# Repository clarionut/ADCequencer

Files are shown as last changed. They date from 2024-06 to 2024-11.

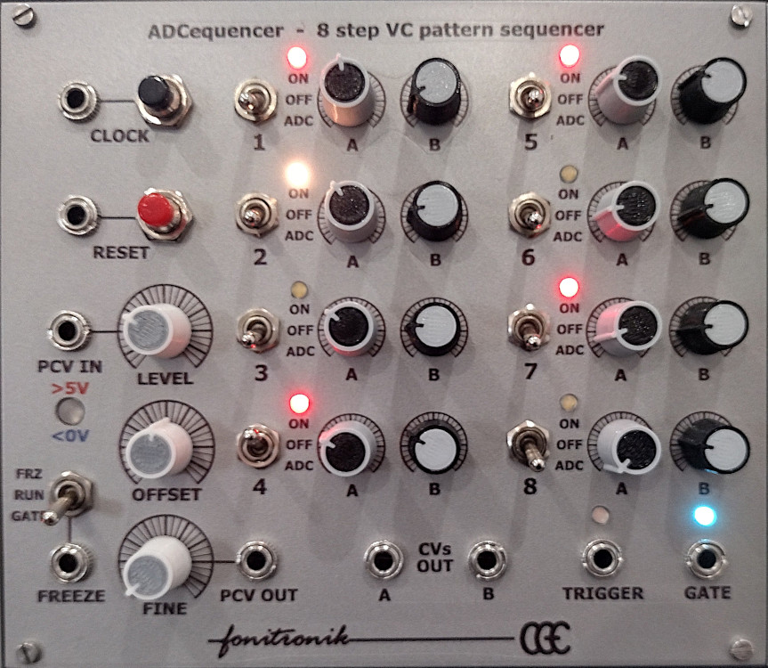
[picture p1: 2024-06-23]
Pictures/ADCequencer.jpg

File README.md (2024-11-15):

# ADCequencer
An 8 step dual channel sequencer with voltage controlled step pattern, based on the [Fonitronik VCPS8](http://www.modular.fonik.de/pdf/VCPS8_doc_v2.pdf) (the predecessor of the MH11) but with significant modifications.

Most obviously, there are two potentiometers to set CV voltages for each step and two CV output channels. This gives considerable flexibility - e.g. controlling two VCOs, a VCO and filter cutoff, or (in conjunction with an external clock divider / analogue switch module) operation as a 16-step sequencer.

Another significant visible change is the addition of a 'freeze' circuit operated by switch or a gate input allowing the ADC to be stopped under voltage control. This gives real value to the gate output from the VCPS8 (which is on continously through a sequence of active steps) as it allows the sequencer pattern to be updated only when the trigger output is low (generally meaning that no note is sounding). This avoids a serious glitchy effect when a step is turned off while it's active.

Cosmetically, the LED arrays have been replaced by red/white common-cathode bicolour LEDs associated with each step (red shows the active steps and white the current step) plus a red/blue common-anode LED as an indicator for out-of-range pattern control voltages.

Behind the scenes there are also significant changes:
- the PCV out-of-range protection circuit in the original is essentially a zener diode crowbar across an op-amp output. This has been replaced by an in-line resistor and Schottky diodes to +5V and ground. The PCV out is not clipped by these, so it's easy to use an external voltmeter to check and adjust the incoming control voltage. The out-of-range LED circuitry is also modified so the LEDs are never reverse biased.
- the Gray-coding circuitry is included but can be bypassed by connecting to an alternative header on the PCB. The CD4030 XOR gates can be omitted altogether if Gray-coding is not required.
- the gate/trigger driver circuit has been significantly revised, doing away with the need for the CD40106 in the original (discussion at [Electro-Music.com](https://electro-music.com/forum/topic-52774-50.html)). A simple RC filter on the base of the trigger-driver transistor removes the very fast pulse from the AND gates which can cause double-triggering. The CD40106 is not needed for the ADC clock either, as the ADC802 contains an inverter gate and just needs an external resistor and capacitor to provide its own clock. The gate and trigger outputs are taken from a dedicated 9V supply rather than the raw 12V supply.

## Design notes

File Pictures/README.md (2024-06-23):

Front copper ground plane fill removed from the PCB picture for clarity. The ground plane is present in the KiCad pcb file.

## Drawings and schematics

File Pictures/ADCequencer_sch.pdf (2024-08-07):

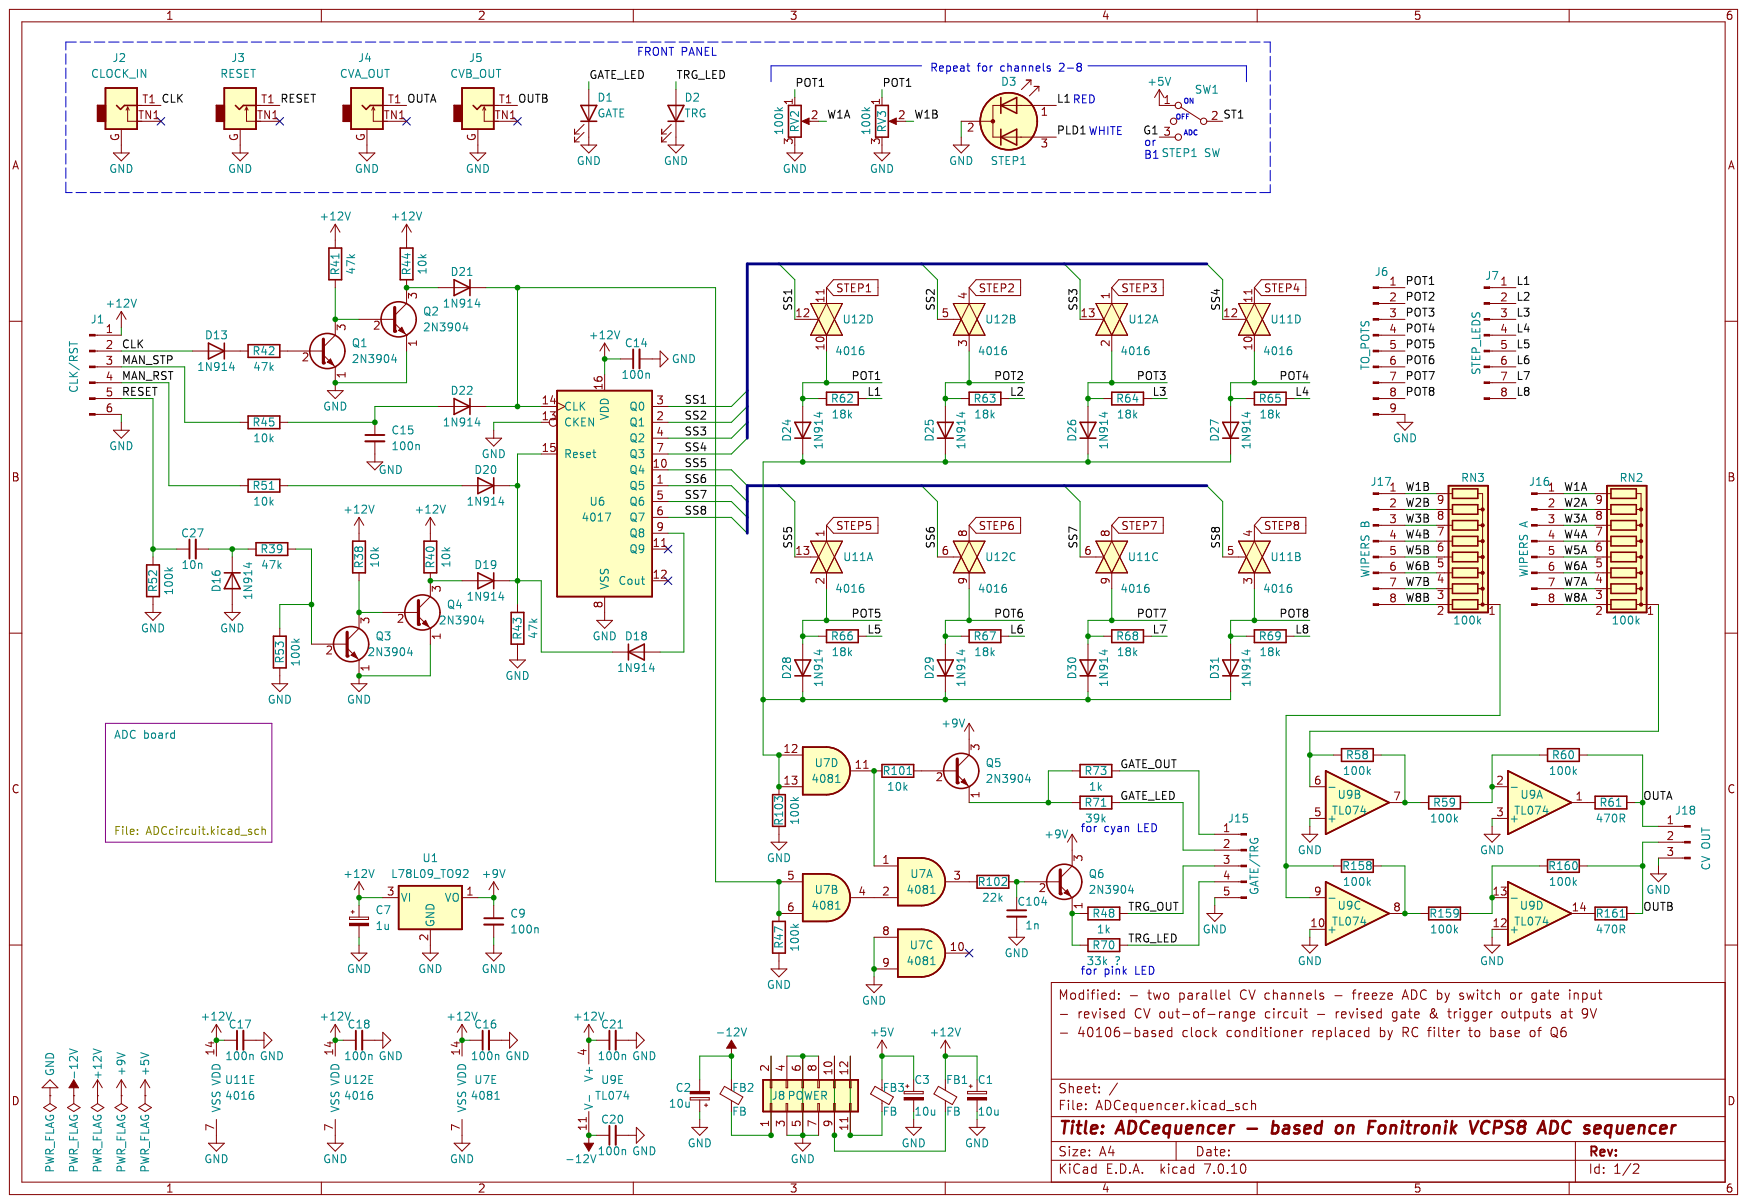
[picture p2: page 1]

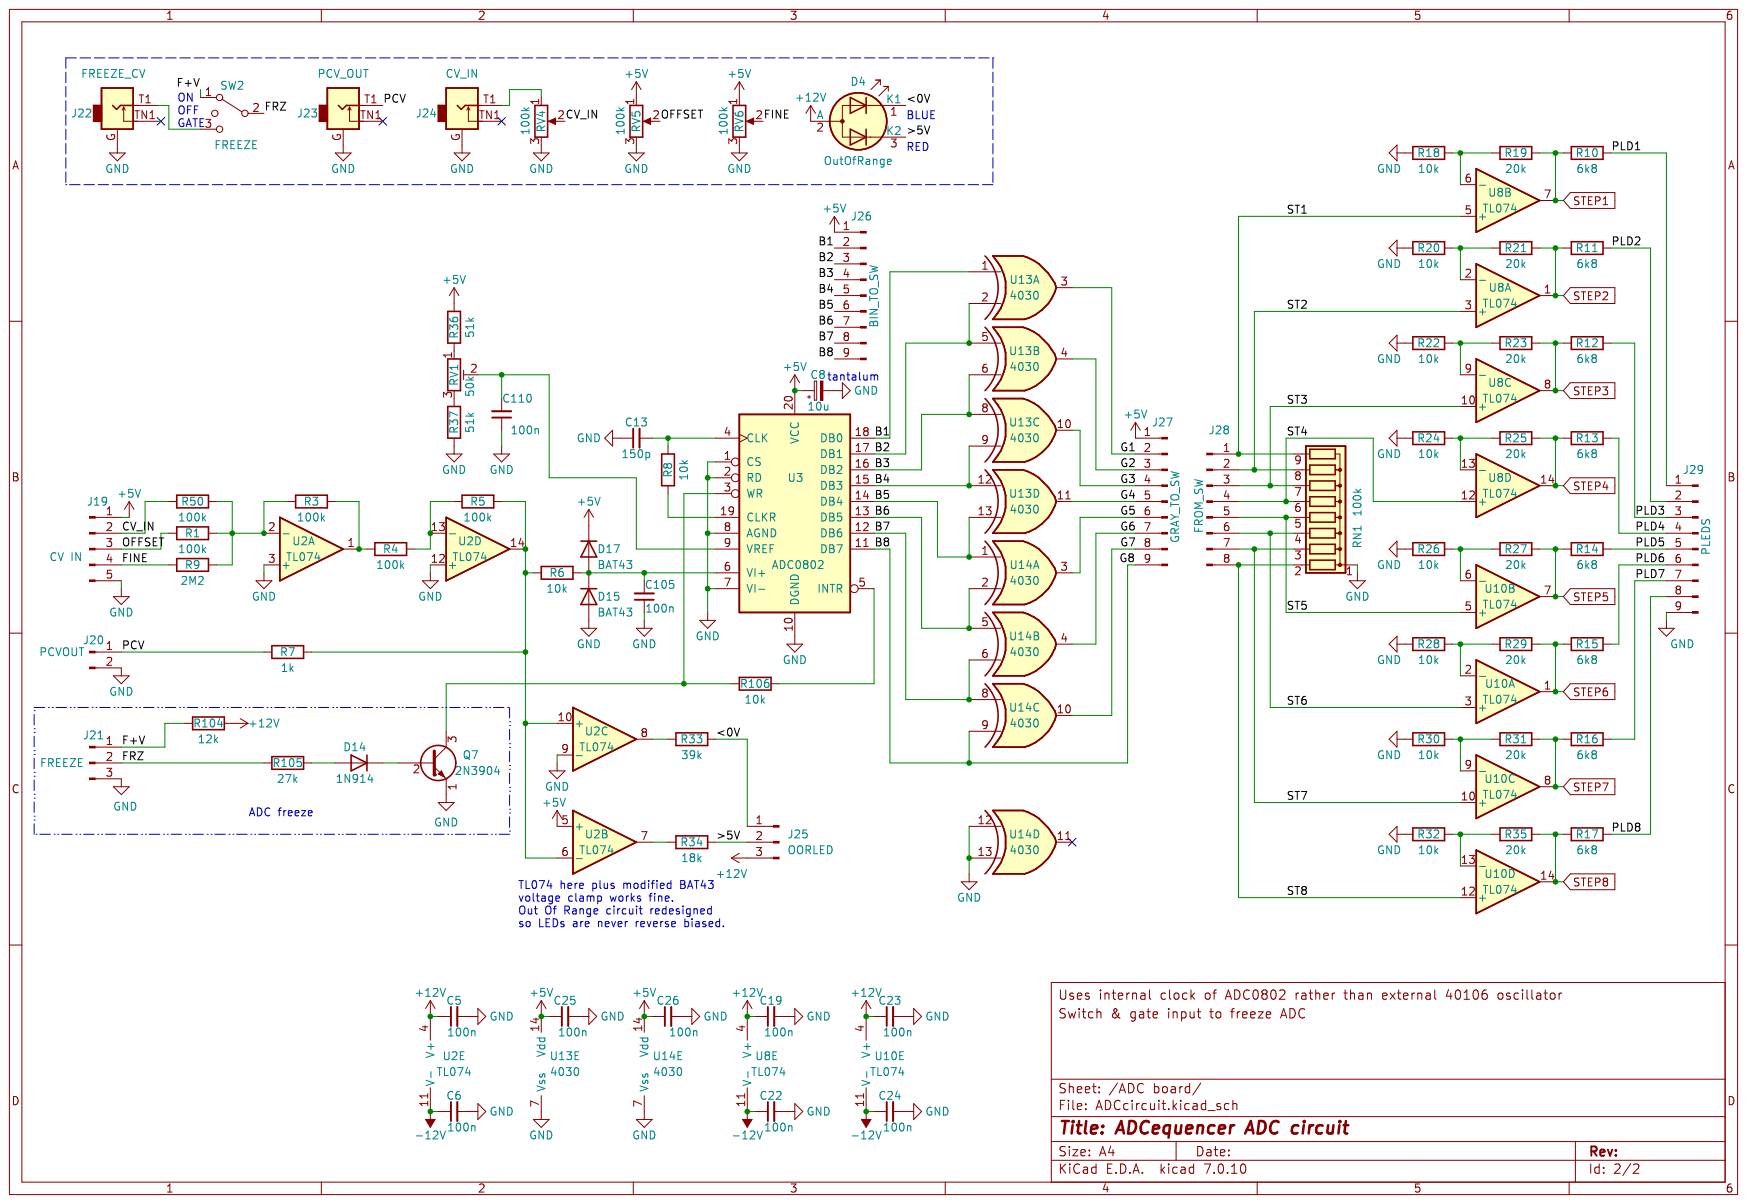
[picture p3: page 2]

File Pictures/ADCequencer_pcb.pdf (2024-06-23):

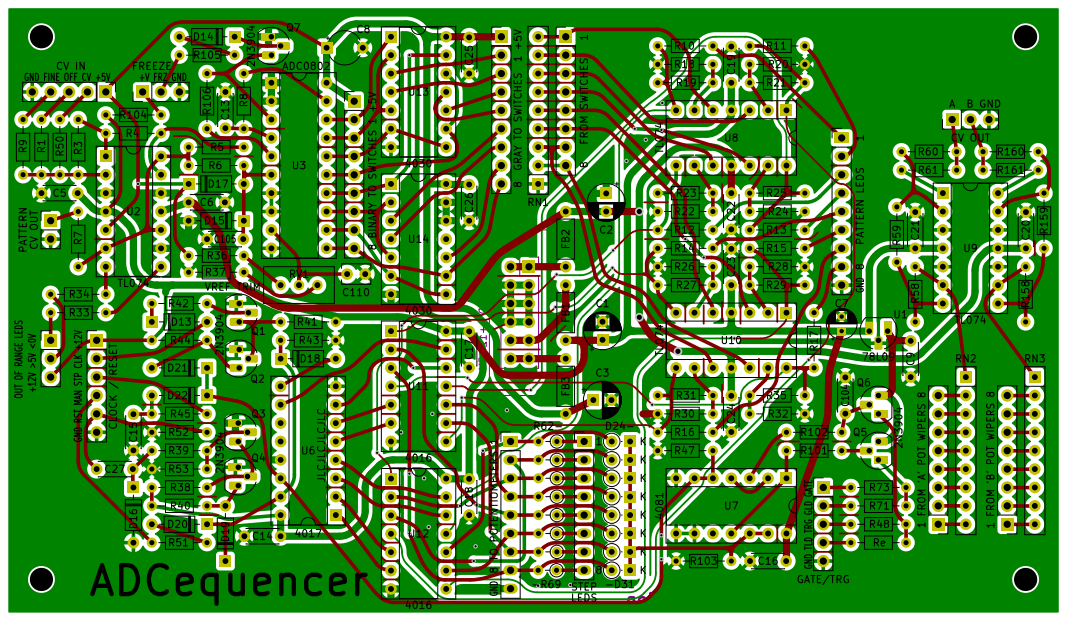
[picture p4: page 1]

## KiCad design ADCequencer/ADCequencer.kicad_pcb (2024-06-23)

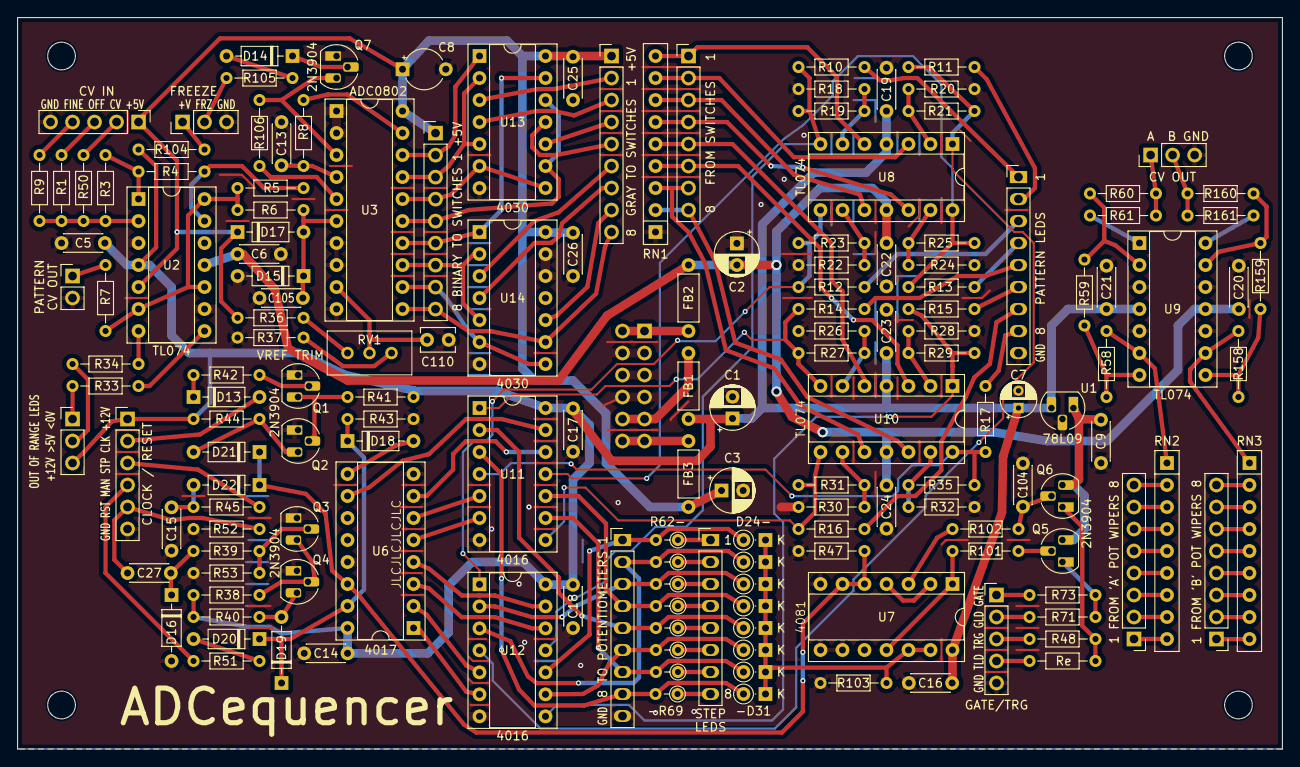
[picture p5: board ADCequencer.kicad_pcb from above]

Board: 2 copper layers, 146.1 x 84.5 mm, 165 parts (1 on the bottom side), 158 nets.

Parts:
C1, C2, C3: 10u; CP_Radial_D5.0mm_P2.50mm
C5, C6, C9, C14, C15, C16, C17, C18, C19, C20, C21, C22, C23, C24, C25, C26, C105: 100n; C_Disc_D4.3mm_W1.9mm_P5.00mm
C7: 1u; CP_Radial_D4.0mm_P2.00mm
C8: 10u; CP_Radial_Tantal_D4.5mm_P5.00mm
C13: 150p; C_Disc_D4.3mm_W1.9mm_P5.00mm
C27: 10n; C_Disc_D4.3mm_W1.9mm_P5.00mm
C104: 1n; C_Disc_D4.3mm_W1.9mm_P5.00mm
C110: 100n; C_Disc_D3.8mm_W2.6mm_P2.50mm
D13, D14, D16, D18, D19, D20, D21, D22: 1N914; D_DO-35_SOD27_P7.62mm_Horizontal
D15, D17: BAT43; D_DO-35_SOD27_P7.62mm_Horizontal
D24, D25, D26, D27, D28, D29, D30, D31: 1N914; D_DO-35_SOD27_P2.54mm_Vertical_KathodeUp
FB1, FB2, FB3: FB; L_Axial_L5.3mm_D2.2mm_P7.62mm_Horizontal_Vishay_IM-1
J1: CLK/RST; PinHeader_1x06_P2.54mm_Vertical
J6: TO_POTS; PinHeader_1x09_P2.54mm_Vertical
J7: STEP_LEDS; PinHeader_1x08_P2.54mm_Vertical
J8: POWER; Power_2x06
J15: GATE/TRG; PinHeader_1x05_P2.54mm_Vertical
J16: WIPERS A; PinHeader_1x08_P2.54mm_Vertical
J17: WIPERS B; PinHeader_1x08_P2.54mm_Vertical
J18: CV OUT; PinHeader_1x03_P2.54mm_Vertical
J19: CV IN; PinHeader_1x05_P2.54mm_Vertical
J20: PCVOUT; PinHeader_1x02_P2.54mm_Vertical
J21: FREEZE; PinHeader_1x03_P2.54mm_Vertical
J25: OORLED; PinHeader_1x03_P2.54mm_Vertical
J26: BIN_TO_SW; PinHeader_1x09_P2.54mm_Vertical
J27: GRAY_TO_SW; PinHeader_1x09_P2.54mm_Vertical
J28: FROM_SW; PinHeader_1x08_P2.54mm_Vertical
J29: PLEDS; PinHeader_1x09_P2.54mm_Vertical
Q1, Q2, Q3, Q4, Q5, Q6, Q7: 2N3904; TO-92_HandSolder
R1, R3, R4, R5, R47, R50, R52, R53, R58, R59, R60, R103, R158, R159, R160: 100k; R_Axial_DIN0204_L3.6mm_D1.6mm_P7.62mm_Horizontal
R6, R8, R18, R20, R22, R24, R26, R28, R30, R32, R38, R40, R44, R45, R51, R101, R106: 10k; R_Axial_DIN0204_L3.6mm_D1.6mm_P7.62mm_Horizontal
R7, R48, R73: 1k; R_Axial_DIN0204_L3.6mm_D1.6mm_P7.62mm_Horizontal
R9: 2M2; R_Axial_DIN0204_L3.6mm_D1.6mm_P7.62mm_Horizontal
R10, R11, R12, R13, R14, R15, R16, R17: 6k8; R_Axial_DIN0204_L3.6mm_D1.6mm_P7.62mm_Horizontal
R19, R21, R23, R25, R27, R29, R31, R35: 20k; R_Axial_DIN0204_L3.6mm_D1.6mm_P7.62mm_Horizontal
R33, R71: 39k; R_Axial_DIN0204_L3.6mm_D1.6mm_P7.62mm_Horizontal
R34: 18k; R_Axial_DIN0204_L3.6mm_D1.6mm_P7.62mm_Horizontal
R36, R37: 51k; R_Axial_DIN0204_L3.6mm_D1.6mm_P7.62mm_Horizontal
R39, R41, R42, R43: 47k; R_Axial_DIN0204_L3.6mm_D1.6mm_P7.62mm_Horizontal
R61, R161: 470R; R_Axial_DIN0204_L3.6mm_D1.6mm_P7.62mm_Horizontal
R62, R63, R64, R65, R66, R67, R68, R69: 18k; R_Axial_DIN0204_L3.6mm_D1.6mm_P2.54mm_Vertical
R102: 22k; R_Axial_DIN0204_L3.6mm_D1.6mm_P7.62mm_Horizontal
R104: 12k; R_Axial_DIN0204_L3.6mm_D1.6mm_P7.62mm_Horizontal
R105: 27k; R_Axial_DIN0204_L3.6mm_D1.6mm_P7.62mm_Horizontal
REF1, REF2, REF3, REF4: Hole_3.2mm; MountingHole_3.2mm_M3
RN1, RN2, RN3: 100k; R_Array_SIP9
RV1: 50k; Potentiometer_Bourns_3296W_Vertical
Re: 39k; R_Axial_DIN0204_L3.6mm_D1.6mm_P7.62mm_Horizontal
U1: L78L09_TO92; TO-92_HandSolder
U2, U8, U9, U10: TL074; DIP-14_W7.62mm_Socket
U3: ADC0802; DIP-20_W7.62mm_Socket
U6: 4017; DIP-16_W7.62mm_Socket
U7: 4081; DIP-14_W7.62mm_Socket
U11, U12: 4016; DIP-14_W7.62mm_Socket
U13, U14: 4030; DIP-14_W7.62mm_Socket

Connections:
+5V: C3.1, C8.1, C25.1, C26.1, D17.1 (K), FB3.1, J19.1, J26.1, J27.1, R36.2, U2.5 (+), U3.20 (VCC), U13.14 (Vdd), U14.14 (Vdd)
+9V: C9.1, Q5.3 (C), Q6.3 (C), U1.1 (VO)
+12V: C1.1, C5.1, C7.1, C14.1, C16.1, C17.1, C18.1, C19.1, C21.1, C23.1, FB1.1, J1.1, J25.3, R38.2, R40.2, R41.2, R44.2, R104.2, U1.3 (VI), U2.4 (V+), U6.16 (VDD), U7.14 (VDD), U8.4 (V+), U9.4 (V+), U10.4 (V+), U11.14 (VDD), U12.14 (VDD)
-12V: C2.2, C6.1, C20.1, C22.1, C24.1, FB2.1, U2.11 (V-), U8.11 (V-), U9.11 (V-), U10.11 (V-)
/ADC board/<0V: J25.1, R33.2
/ADC board/>5V: J25.2, R34.2
/ADC board/B1: J26.2, U3.18 (DB0), U13.1
/ADC board/B2: J26.3, U3.17 (DB1), U13.2, U13.5
/ADC board/B3: J26.4, U3.16 (DB2), U13.6, U13.8
/ADC board/B4: J26.5, U3.15 (DB3), U13.9, U13.12
/ADC board/B5: J26.6, U3.14 (DB4), U13.13, U14.1
/ADC board/B6: J26.7, U3.13 (DB5), U14.2, U14.5
/ADC board/B7: J26.8, U3.12 (DB6), U14.6, U14.8
/ADC board/B8: J26.9, J27.9, U3.11 (DB7), U14.9
/ADC board/CV_IN: J19.2, R50.1
/ADC board/F+V: J21.1, R104.1
/ADC board/FINE: J19.4, R9.1
/ADC board/FRZ: J21.2, R105.1
/ADC board/G1: J27.2, U13.3
/ADC board/G2: J27.3, U13.4
/ADC board/G3: J27.4, U13.10
/ADC board/G4: J27.5, U13.11
/ADC board/G5: J27.6, U14.3
/ADC board/G6: J27.7, U14.4
/ADC board/G7: J27.8, U14.10
/ADC board/OFFSET: J19.3, R1.1
/ADC board/PCV: J20.1, R7.1
/ADC board/PLD1: J29.1, R10.2
/ADC board/PLD2: J29.2, R11.2
/ADC board/PLD3: J29.3, R12.2
/ADC board/PLD4: J29.4, R13.2
/ADC board/PLD5: J29.5, R14.2
/ADC board/PLD6: J29.6, R15.2
/ADC board/PLD7: J29.7, R16.2
/ADC board/PLD8: J29.8, R17.2
/ADC board/ST1: J28.1, RN1.9 (R8), U8.5 (+)
/ADC board/ST2: J28.2, RN1.8 (R7), U8.3 (+)
/ADC board/ST3: J28.3, RN1.7 (R6), U8.10 (+)
/ADC board/ST4: J28.4, RN1.6 (R5), U8.12 (+)
/ADC board/ST5: J28.5, RN1.5 (R4), U10.5 (+)
/ADC board/ST6: J28.6, RN1.4 (R3), U10.3 (+)
/ADC board/ST7: J28.7, RN1.3 (R2), U10.10 (+)
/ADC board/ST8: J28.8, RN1.2 (R1), U10.12 (+)
/CLK: D13.2 (A), J1.2
/GATE_LED: J15.2, R71.2
/GATE_OUT: J15.1, R73.2
/L1: J7.1, R62.1
/L2: J7.2, R63.1
/L3: J7.3, R64.1
/L4: J7.4, R65.1
/L5: J7.5, R66.1
/L6: J7.6, R67.1
/L7: J7.7, R68.1
/L8: J7.8, R69.1
/MAN_RST: J1.4, R51.1
/MAN_STP: J1.3, R45.1
/OUTA: J18.1, R60.2, R61.2
/OUTB: J18.2, R160.2, R161.2
/POT1: D24.2 (A), J6.1, R62.2, U12.10
/POT2: D25.2 (A), J6.2, R63.2, U12.3
/POT3: D26.2 (A), J6.3, R64.2, U12.2
/POT4: D27.2 (A), J6.4, R65.2, U11.10
/POT5: D28.2 (A), J6.5, R66.2, U11.2
/POT6: D29.2 (A), J6.6, R67.2, U12.9
/POT7: D30.2 (A), J6.7, R68.2, U11.9
/POT8: D31.2 (A), J6.8, R69.2, U11.3
/RESET: C27.1, J1.5, R52.2
/SS1: U6.3 (Q0), U12.12
/SS2: U6.2 (Q1), U12.5
/SS3: U6.4 (Q2), U12.13
/SS4: U6.7 (Q3), U11.12
/SS5: U6.10 (Q4), U11.13
/SS6: U6.1 (Q5), U12.6
/SS7: U6.5 (Q6), U11.6
/SS8: U6.6 (Q7), U11.5
/TRG_LED: J15.4, Re.2
/TRG_OUT: J15.3, R48.2
/W1A: J16.1, RN2.9 (R8)
/W1B: J17.1, RN3.9 (R8)
/W2A: J16.2, RN2.8 (R7)
/W2B: J17.2, RN3.8 (R7)
/W3A: J16.3, RN2.7 (R6)
/W3B: J17.3, RN3.7 (R6)
/W4A: J16.4, RN2.6 (R5)
/W4B: J17.4, RN3.6 (R5)
/W5A: J16.5, RN2.5 (R4)
/W5B: J17.5, RN3.5 (R4)
/W6A: J16.6, RN2.4 (R3)
/W6B: J17.6, RN3.4 (R3)
/W7A: J16.7, RN2.3 (R2)
/W7B: J17.7, RN3.3 (R2)
/W8A: J16.8, RN2.2 (R1)
/W8B: J17.8, RN3.2 (R1)
GND: C1.2, C2.1, C3.2, C5.2, C6.2, C7.2, C8.2, C9.2, C13.1, C14.2, C15.2, C16.2, C17.2, C18.2, C19.2, C20.2, C21.2, C22.2, C23.2, C24.2, C25.2, C26.2, C104.2, C105.1, C110.1, D15.2 (A), D16.2 (A), J1.6, J6.9, J8.3, J8.4, J8.5, J8.6, J8.7, J8.8, J15.5, J18.3, J19.5, J20.2, J21.3, J29.9, Q1.1 (E), Q2.1 (E), Q3.1 (E), Q4.1 (E), Q7.1 (E), R18.1, R20.1, R22.1, R24.1, R26.1, R28.1, R30.1, R32.1, R37.1, R43.1, R47.1, R52.1, R53.1, R103.1, RN1.1 (common), U1.2 (GND), U2.3 (+), U2.9 (-), U2.12 (+), U3.1 (CS), U3.2 (RD), U3.7 (VI-), U3.8 (AGND), U3.10 (DGND), U6.8 (VSS), U6.13 (CKEN), U7.7 (VSS), U7.8, U7.9, U9.3 (+), U9.5 (+), U9.10 (+), U9.12 (+), U11.7 (VSS), U12.7 (VSS), U13.7 (Vss), U14.7 (Vss), U14.12, U14.13
unnamed: D13.1 (K), R42.1
unnamed: D14.2 (A), R105.2
unnamed: D14.1 (K), Q7.2 (B)
unnamed: C105.2, D15.1 (K), D17.2 (A), R6.2, U3.6 (VI+)
unnamed: C27.2, D16.1 (K), R39.1
unnamed: D18.2 (A), U6.9 (Q8)
unnamed: D18.1 (K), D19.1 (K), D20.1 (K), R43.2, U6.15 (Reset)
unnamed: D19.2 (A), Q4.3 (C), R40.1
unnamed: D20.2 (A), R51.2
unnamed: D21.2 (A), Q2.3 (C), R44.1
unnamed: D21.1 (K), D22.1 (K), R47.2, U6.14 (CLK), U7.5, U7.6
unnamed: C15.1, D22.2 (A), R45.2
unnamed: D24.1 (K), D25.1 (K), D26.1 (K), D27.1 (K), D28.1 (K), D29.1 (K), D30.1 (K), D31.1 (K), R103.2, U7.12, U7.13
unnamed: FB2.2, J8.1, J8.2
unnamed: FB1.2, J8.9, J8.10
unnamed: FB3.2, J8.11, J8.12
unnamed: Q1.2 (B), R42.2
unnamed: Q1.3 (C), Q2.2 (B), R41.1
unnamed: Q3.2 (B), R39.2, R53.2
unnamed: Q3.3 (C), Q4.2 (B), R38.1
unnamed: Q5.2 (B), R101.2
unnamed: Q5.1 (E), R71.1, R73.1
unnamed: C104.1, Q6.2 (B), R102.2
unnamed: Q6.1 (E), R48.1, Re.1
unnamed: Q7.3 (C), R106.1, U3.3 (WR)
unnamed: R3.2, R4.1, U2.1
unnamed: R33.1, U2.8
unnamed: R34.1, U2.7
unnamed: R36.1, RV1.1
unnamed: R37.2, RV1.3
unnamed: R58.2, R59.1, U9.7
unnamed: R61.1, U9.1
unnamed: R101.1, U7.1, U7.11
unnamed: R102.1, U7.3
unnamed: R158.2, R159.1, U9.8
unnamed: R161.1, U9.14
unnamed: R58.1, RN2.1 (common), U9.6 (-)
unnamed: R158.1, RN3.1 (common), U9.9 (-)
unnamed: R1.2, R3.1, R9.2, R50.2, U2.2 (-)
unnamed: R5.2, R6.1, R7.2, U2.6 (-), U2.10 (+), U2.14
unnamed: R4.2, R5.1, U2.13 (-)
unnamed: C13.2, R8.2, U3.4 (CLK)
unnamed: R8.1, U3.19 (CLKR)
unnamed: R106.2, U3.5 (INTR)
unnamed: C110.2, RV1.2, U3.9 (VREF)
unnamed: U7.2, U7.4
unnamed: R20.2, R21.1, U8.2 (-)
unnamed: R18.2, R19.1, U8.6 (-)
unnamed: R22.2, R23.1, U8.9 (-)
unnamed: R24.2, R25.1, U8.13 (-)
unnamed: R59.2, R60.1, U9.2 (-)
unnamed: R159.2, R160.1, U9.13 (-)
unnamed: R28.2, R29.1, U10.2 (-)
unnamed: R26.2, R27.1, U10.6 (-)
unnamed: R30.2, R31.1, U10.9 (-)
unnamed: R32.2, R35.1, U10.13 (-)
STEP1: R10.1, R19.2, U8.7, U12.11
STEP2: R11.1, R21.2, U8.1, U12.4
STEP3: R12.1, R23.2, U8.8, U12.1
STEP4: R13.1, R25.2, U8.14, U11.11
STEP5: R14.1, R27.2, U10.7, U11.1
STEP6: R15.1, R29.2, U10.1, U12.8
STEP7: R16.1, R31.2, U10.8, U11.8
STEP8: R17.1, R35.2, U10.14, U11.4
